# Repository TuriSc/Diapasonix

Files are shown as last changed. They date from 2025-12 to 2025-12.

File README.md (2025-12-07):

# Diapasonix — Portable Electronic Instrument and MIDI Controller

Diapasonix is a portable electronic musical instrument and MIDI controller that is played similarly to a stringed instrument. It features a capacitive touchpad fretboard, I²S audio output, and a built-in synthesizer with chainable audio effects powered by the AMY synthesis engine.

Its four-string, six-fret layout (24 touch points total) can be set up to match traditional stringed instruments like guitar, bass, ukulele, violin, double bass, banjo, and so on. If you can play any of these instruments, you can play Diapasonix!

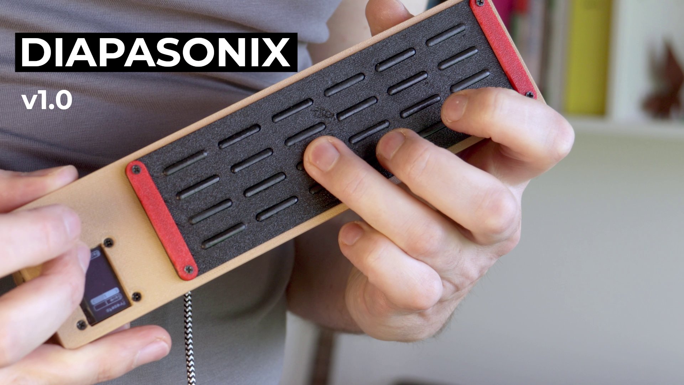
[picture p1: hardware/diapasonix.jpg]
YouTube Video (https://youtu.be/DMDRZ1dwdG4 "Diapasonix")

[Video link](https://youtu.be/DMDRZ1dwdG4)

## Features

* Raspberry Pi Pico 2 (RP2350) as the central unit
* Capacitive touchpad fretboard with 4 strings and 6 frets
* AMY synthesis engine with 256 built-in presets (128 Juno-6 patches, 128 DX7 patches)
* I²S audio output with built-in speaker support and amplified audio output
* SSD1306 OLED display
* Directional switch for navigation and parameter selection
* Multiple audio effects: reverb, chorus, echo/delay, distortion, and low-pass filter
* Per-string tuning and capo transposing
* Strumming mode and tapping mode
* Left-handed mode support
* MIDI output support (optional, can be disabled to use USB as stdio)
* Battery level monitoring and low battery indicator
* Automatic storage and retrieval of settings
* Four user presets for saving and recalling complete instrument configurations
* Volume control
* Display contrast control with automatic dimming

## Synth Engine and Instrument Presets

Diapasonix uses the [AMY](https://github.com/shorepine/amy) synthesis engine, a high-performance fixed-point music synthesizer library. AMY supports multiple synthesis types, but currently Diapasonix offers only the ability to recall any of the 256 built-in presets: 128 patches based on the Juno-6 synthesizer and 128 patches based on the DX7 synthesizer. Each preset has a number (0-255) for easy selection. Pressing the center button while the patch number is selected chooses a patch at random.

## Audio Effects

Diapasonix includes five audio effects that can be enabled and configured:

### Reverb
* Liveness control (room size)
* Damping control
* Crossover frequency

### Chorus
* Maximum delay time
* LFO frequency
* Modulation depth

### Echo/Delay
* Delay time (10-200 ms)
* Feedback amount
* Filter coefficient

### Filter
* Low-pass filter with adjustable cutoff frequency (20 Hz - 20 kHz)
* Resonance (Q factor) control

### Distortion
* Level control (0.0 to 1.0) - amount of distortion effect
* Gain control (1.0 to 2.0) - drive/gain before distortion

## Fretboard and Playing Modes

The fretboard consists of four strings, each with six frets, providing a total of 24 touch points. Two playing modes are available:

**Strumming Mode**: Notes trigger only when you strum across the strings after placing your fingers on frets. In this mode, the last row of frets functions as open strings. When you hold a fret on a string and strum a fret on that last row, the corresponding note of the held fret will play. This mode mimics traditional guitar playing, allows for chord playing, and provides more expressive control.

**Tapping Mode**: Notes trigger immediately when any fret is touched. In this mode, the last row of frets is treated as one more fret on the board, allowing you to continue playing up the string.

The instrument also supports per-string tuning and a capo function for transposition.

## Navigation and Controls

A directional switch (5-way navigation switch) is used to navigate menus and adjust parameters:

* Navigate through menu items using the directional pad
* Press the center button to enter/select
* Long-press the center button to exit or access secondary functions
* Adjust parameter values using directional controls

## Settings

From the settings screen, you can configure:

* **Playing Mode**: Toggle between strumming and tapping modes
* **Left-handed Mode**: Flip both the screen and the entire fretboard orientation, allowing left-handed players to use the instrument naturally
* **Volume**: Adjust output volume (0-8 range)
* **Display Contrast**: Adjust OLED brightness or enable automatic dimming

## Tuning

The tuning screen allows you to:

* Set individual string pitch (default: E2, A2, D3, G3)
* Adjust capo position for transposition
* Fine-tune each string independently

## Presets

Diapasonix includes a preset system that allows you to save and recall complete instrument configurations. Each preset stores a snapshot of:

* Current synth patch number
* All effect states (on/off) and their parameters:
  * Reverb (liveness, damping, crossover)
  * Chorus (max delay, LFO frequency, depth)
  * Echo/Delay (delay time, feedback, filter coefficient)
  * Distortion (level, gain)
  * Filter (cutoff frequency, resonance)
* String tuning (individual pitch for each string)
* Capo position
* Playing mode (strumming or tapping)

## Automatic Save

Diapasonix automatically stores the current settings into its flash memory, with a configurable delay (default 10 seconds) to minimize flash wear. Stored settings are loaded automatically at startup. The Pico onboard LED will flash briefly when data is being written to flash memory. There is a very short gap in the audio output, barely audible, when data is being written to flash.

## Defaults Configuration

All advanced user-configurable options and defaults are defined in the file [config.h](config.h). You can, for example, change pin numbers, MPR121 sensitivity, timing-related values, effect defaults, and enable or disable MIDI output. If you want to change any default configuration options, you'll need to build the sources and generate your own uf2 file to flash to the Pico 2.

## Compiling

Building the sources requires the Raspberry Pi Pico SDK.

```sh
git clone https://github.com/TuriSc/Diapasonix.git
cd Diapasonix
git submodule update --init --recursive
mkdir build && cd build
cmake -DPICO_PLATFORM=rp2350 ..
make
```

## Bill of Materials

* Raspberry Pi Pico 2 (RP235x)
* 2x MPR121 (touch sensors)
* MAX98357 I²S DAC (or similar)
* SSD1306 OLED display (128x64, 0.96")
* Directional switch (5-way navigation switch)
* Speaker (4Ω 3W recommended, but 8Ω 2W is fine too)
* 3.5mm audio jack, switched
* 18650 Lithium battery
* One pair of springs for 18650 battery
* TP4056 (charger module)
* Power switch
* Custom PCB (can be swapped for a diy solution)
* Electrical wire and connectors
* 3D-printed enclosure (printable files are provided, as well as OpenSCAD sources)

## Schematic

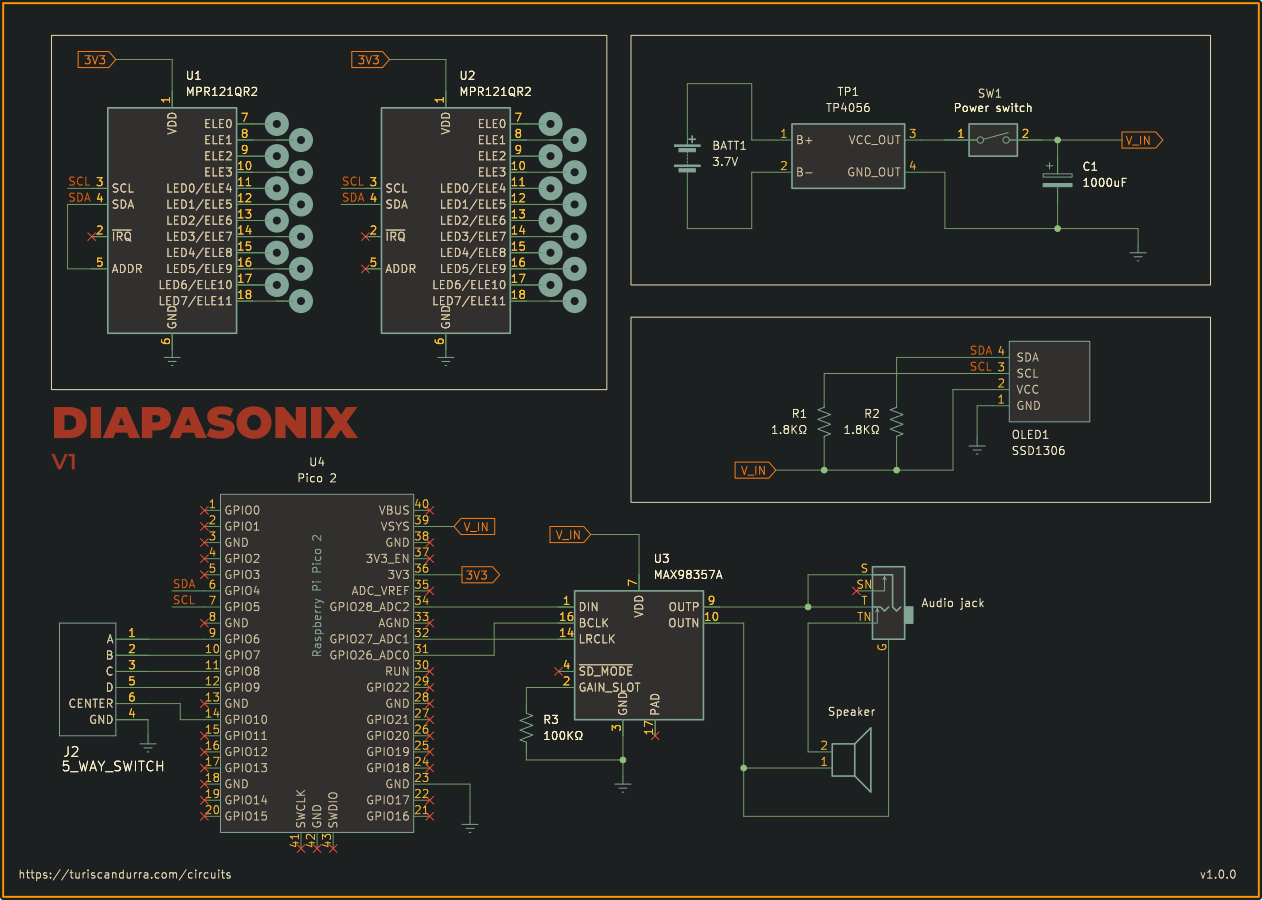
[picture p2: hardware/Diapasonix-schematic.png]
Diapasonix schematic


[PDF version](hardware/Diapasonix-schematic.pdf)

## Construction

I have not yet put together a step-by-step guide to assemble the Diapasonix. I might want to wait until we get to a stable version. I'm changing components and overall design and breaking things as I move. The current capacitive fretboard might undergo a major re-engineering.
One note about the v1 design: the frets are 3d-printed, then dipped in conductive silver paint, and finally coated with a single layer of nail polish. They react very well to even the gentlest of touches.

## Known Limitations

* Synthesizer parameter configuration (beyond patch selection) is planned for future releases.
* Velocity detection is not currently implemented.
* Echo delay is limited to 200ms maximum due to RAM constraints on RP2350.
* A Raspberry Pi Pico (RP2040) will work but with very poor performance, as the audio output will crackle noticeably.
* This is an early prototype. Expect breaking changes.

## Disclaimer

Diapasonix is an original, non‑commercial work created by Turi Scandurra for educational and hobbyist purposes only. The code, schematics, and documentation are provided "as‑is" without any warranties, express or implied.

The author does not claim ownership of any patents that may be relevant to the designs or implementations herein, nor does the author guarantee that the project does not infringe any existing patents, copyrights, trademarks, or other intellectual‑property rights. Users assume all risk associated with the use, modification, or distribution of this material.

By using, copying, or distributing this project you acknowledge that you have read and understood this disclaimer and agree to do so at your own discretion and responsibility.

## More Information

For more information and similar projects, visit [turiscandurra.com/circuits](https://turiscandurra.com/circuits/)

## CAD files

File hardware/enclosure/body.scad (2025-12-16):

include <Diapasonix.scad>
include <shell.scad>

module body(){
    difference(){
        union(){
            shell();
            shell_inner_supports();
        }
        // BOOTSEL opening
        translate([neck_w - bootsel_x, neck_d / 2 - bootsel_y, bootsel_z])
        rotate([0, 0, -90])
        cylinder(h = bootsel_h, r = bootsel_r);
        
        // Tray opening
        margin = pcb_clearance;
        translate([neck_w - tray_inner_w - margin, neck_r1 - margin, 0])
        rotate([0, 90, 0])
        linear_extrude(tray_inner_w + margin)
        intersection(){
            circle(neck_r1 - tray_m + margin, $fn = resolution);
            
            translate([neck_r1 - tray_m - tray_h, -tray_w / 2, 0])
            square([neck_r1 * 2, tray_w + margin * 2]);
        }
        
        // Eyelet insets
        translate([neck_w - wall_d * 2, neck_r1 - margin, 0])
        translate([wall_d * 1.5 - pcb_clearance, tray_w / 2 + tray_eyelet_y_offset, tray_eyelet_z])
        rotate([90, 0, 90])
        linear_extrude(wall_d / 2 + pcb_clearance)
        hull(){
            circle(eyelet_r + pcb_clearance, $fn = resolution);
            translate([-eyelet_r - pcb_clearance, -eyelet_r - pcb_clearance, 0])
            square([eyelet_square_w, eyelet_square_d + pcb_clearance * 2]);
        }
        
        translate([neck_w - wall_d * 2, neck_r1 - margin, 0])
        translate([wall_d * 1.5 - pcb_clearance, -tray_w / 2 - tray_eyelet_y_offset, tray_eyelet_z])
        rotate([-90, 0, -90])
        linear_extrude(wall_d / 2 + pcb_clearance)
        hull(){
            circle(eyelet_r + pcb_clearance, $fn = resolution);
            translate([-eyelet_r - pcb_clearance, -eyelet_r - pcb_clearance, 0])
            square([eyelet_square_w, eyelet_square_d + pcb_clearance * 2]);
        }
        
        // Eyelet screw holes
        translate([neck_w - wall_d * 2, neck_r1 - margin, 0])
        translate([0, tray_w / 2 + tray_eyelet_y_offset, tray_eyelet_z])
        rotate([90, 0, 90])
        translate([0, 0, eyelet_countersunk_z])
        cylinder(h = screw_hole_depth, r = screw_hole_r, $fn = 64);
        
        translate([neck_w - wall_d * 2, neck_r1 - margin, 0])
        translate([0, -tray_w / 2 - tray_eyelet_y_offset, tray_eyelet_z])
        rotate([-90, 0, -90])
        translate([0, 0, eyelet_countersunk_z])
        cylinder(h = screw_hole_depth, r = screw_hole_r, $fn = 64);
        
        // Speaker holes
        translate([neck_w - shell_battery_offset_x + speaker_spacing, neck_d / 2, -neck_r1])
        for (a = [0:7]) {
            rotate(45 * a)
            translate([11, 0, 5])
            cylinder(h = 10, r = 1.4, center = true);
            if(a % 2 == 0){
                rotate(45 * a)
                translate([4.5, 0, 5])
                cylinder(h = 10, r = 1.4, center = true);
            }
        }
        
        // Power switch opening
        translate([neck_w - power_switch_x_offset, neck_d/2,-neck_h])
        cylinder(h=5, r=power_switch_r);
        
        // Audio jack opening
        translate([0, neck_d/2,-jack_z_offset])
        rotate([0,90,0])
        cylinder(h=20, r=jack_r);
    }
    
    // Top face
    difference(){
        union(){
            translate([0, 0, -wall_d])
            cube([neck_w, neck_d, wall_d]);
            
            // Navigation switch support
            translate([neck_w - oled_pos_x + nav_switch_pos_x_offset + nav_switch_pos_y_offset, neck_d / 2 - nav_switch_pos_y_base - wall_d, -nav_switch_pos_h - wall_d])
            cube([nav_switch_cross_w, nav_switch_cross_d - wall_d * 2, wall_d + nav_switch_pos_h]);
            
            // OLED underside supports
            translate([neck_w - oled_pos_x - 5.5, neck_d / 2 - oled_support_top_offset, -wall_d - 2])
            linear_extrude(wall_d)
            polygon([[0, 0], [9, 0], [0, 9]]);
            
            translate([neck_w - oled_pos_x - 5.5, neck_d / 2 + oled_support_bottom_offset, -wall_d - 2])
            linear_extrude(wall_d)
            polygon([[0, 0], [0, 9], [9, 9]]);
            
            translate([neck_w - oled_ribbon_x + oled_ribbon_w, neck_d / 2 - oled_support_top_offset, -wall_d - 2])
            linear_extrude(wall_d)
            polygon([[0, 0], [9, 0], [9, 9]]);
            
            translate([neck_w - oled_ribbon_x + oled_ribbon_w, neck_d / 2 + oled_support_bottom_offset, -wall_d - 2])
            linear_extrude(wall_d)
            polygon([[9, 0], [0, 9], [9, 9]]);
        }
        
        // PCB opening
        translate([wall_d + 2, wall_d + pcb_pos_y_offset + 6.5, -wall_d])
        cube([pcb_w - 4, pcb_d - 13, wall_d]);
    
        // Screw holes, PCB
        translate([wall_d + pcb_screw_offset_x, wall_d + pcb_screw_offset_y + screw_pos_y_offset, -threaded_insert_h])
        cylinder(r = threaded_insert_r, h = threaded_insert_h, $fn = 64);
        
        translate([wall_d + pcb_screw_offset_x, wall_d + pcb_screw_offset_y_bottom + screw_pos_y_offset, -threaded_insert_h])
        cylinder(r = threaded_insert_r, h = threaded_insert_h, $fn = 64);
        
        translate([wall_d + pcb_w - pcb_screw_offset_x, wall_d + pcb_screw_offset_y + screw_pos_y_offset, -threaded_insert_h])
        cylinder(r = threaded_insert_r, h = threaded_insert_h, $fn = 64);
        
        translate([wall_d + pcb_w - pcb_screw_offset_x, wall_d + pcb_screw_offset_y_bottom + screw_pos_y_offset, -threaded_insert_h])
        cylinder(r = threaded_insert_r, h = threaded_insert_h, $fn = 64);
        
        // Screw holes, UI
        translate([neck_w - ui_screw_x_offset, wall_d + pcb_screw_offset_y + screw_pos_y_offset, -threaded_insert_h])
        cylinder(r = threaded_insert_r, h = threaded_insert_h, $fn = 64);
        translate([neck_w - ui_screw_x_offset, neck_d / 2 + oled_screw_y1, -threaded_insert_h])
        cylinder(r = threaded_insert_r, h = threaded_insert_h, $fn = 64);
        
        // OLED opening
        translate([neck_w - oled_pos_x - 5.1, neck_d / 2 - oled_opening_top_offset, -2])
        cube([oled_opening_w, oled_opening_d, 3]);
        
        // Navigation switch opening
        translate([neck_w - oled_pos_x + nav_switch_pos_x_offset + 0.2, neck_d / 2 - nav_switch_pos_y_base, -3.8])
        cube([10.4, 10.8, 10.4]);
    }

    // Standoffs, PCB
    translate([wall_d + pcb_screw_offset_x, wall_d + pcb_screw_offset_y + screw_pos_y_offset, -wall_d - 2])
    standoff(2);
    
    translate([wall_d + pcb_screw_offset_x, wall_d + pcb_screw_offset_y_bottom + screw_pos_y_offset, -wall_d - 2])
    standoff(2);
    
    translate([wall_d + pcb_w - pcb_screw_offset_x, wall_d + pcb_screw_offset_y + screw_pos_y_offset, -wall_d - 2])
    standoff(2);
    
    translate([wall_d + pcb_w - pcb_screw_offset_x, wall_d + pcb_screw_offset_y_bottom + screw_pos_y_offset, -wall_d - 2])
    standoff(2);
    
    // Standoffs, UI
    translate([neck_w - ui_screw_x_offset, neck_d / 2 + oled_screw_y1, -wall_d - 2])
    standoff(2);
    translate([neck_w - ui_screw_x_offset, wall_d + pcb_screw_offset_y + screw_pos_y_offset, -wall_d - 2])
    standoff(2);
}

if(is_undef(is_root)) {
    body();
}

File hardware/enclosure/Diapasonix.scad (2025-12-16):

// v1.1.0
// To be cleaned up, as I tried different construction
// methods and left a trail of unused variables.

resolution = 128; // Adjust as needed
use_threaded_inserts = true;

n_strings = 4;
n_pods_per_string = 6;

pod_w = 25;
pod_d = 10;
pod_h = 2.4;

fret_w = 18;
fret_d = 2;
fret_h = 4; // min is fret_r
fret_r = fret_d/2;
fret_brim_d = 2.2;
fret_brim_h = 0.6;

silicone_h = 1;

magnet_r = 1 + 0.25; // Including clearance
magnet_h = 1 + 0.4; // Including clearance

ridge_d = 2.8;
ridge_h = 3;

ui_w = 58;
capo_offset_w = 7;

wall_d = 2.0;

screw_hole_r = 1.2;
threaded_insert_r = 1.9;
threaded_insert_h = 4;
standoff_r = 3;
so_clr = 0.4;

neck_w = pod_w*n_pods_per_string+ui_w;
neck_d = pod_d*n_strings+ridge_d*n_strings + 2.6;

neck_r1=neck_d/2;
neck_r2=36;
neck_h = neck_r1;

tongue = 1.2;
tongue_h = 4.0;
r_clearance = .4;

tray_w = 25;
tray_h = 20;
tray_m = 2;

neck_top_h = pod_h+ridge_h+fret_r;

// Clearances and tolerances
pcb_clearance = 0.4;
pcb_clearance_2x = pcb_clearance * 2;
header_clearance = 0.4;
switch_clearance = 0.8;
switch_clearance_small = 0.4;
groove_depth = 1.6;
countersunk_depth = 0.4;
countersunk_offset = -0.8;
render_compensation = 0.01;
countersunk_height = 3.2;
screw_hole_depth = 8;

// PCB dimensions
pcb_w = 159.790;
pcb_d = 47.675;
pcb_h = 1;
pcb_screw_offset_x = 4.730;
pcb_screw_offset_y = 3.465;
pcb_screw_offset_y_bottom = 47.625 - 3.465;

// Header dimensions
header_w = 2.75;
header_l = 34;
header_h = 3;
header_oled_l = 12;
header_pos_x = 3.38;
header_pos_y = 4.92;
header_pos_y_offset = 3;
pcb_edge_offset = 1; // Offset from PCB edge
pcb_pos_y_offset = 1; // Y offset for PCB position
screw_pos_y_offset = 1; // Y offset for screw positions

// Capacitive headers cover
cap_header_cover_r = 3.6;
cap_header_cover_dist = 42.66;
cap_header_cover_groove_l = 30.70;
cap_header_cover_screw_y1 = 3.465 + 1;
cap_header_cover_screw_y2_offset = 2.5;
cap_header_cover_top_z = 2;
cap_header_cover_top_h = 2;
cap_header_cover_bottom_z = -10;
cap_header_cover_bottom_h = 10;

// Top opening
top_opening_x = 12.4;
top_opening_w = 137.8;
top_opening_d = 40;
top_opening_y_offset = 4.0;
fret_cutout_x_offset = 2;
fret_cutout_z = 1.4;
fret_spacing = 22.88;

// OLED dimensions
oled_w = 17;
oled_d = 25;
oled_clearance = 0.2;
oled_opening_w = oled_w + oled_clearance * 2;
oled_opening_d = oled_d + oled_clearance * 2;
oled_opening_z = 3;
oled_pos_x = 28.5;
oled_pos_y_offset = 2.7;
oled_support_top_offset = 5.2;
oled_support_bottom_offset = 14.2;
oled_opening_top_offset = 4.6;
oled_screw_y1 = 20.2;
oled_screw_y2 = 1.7;
oled_ribbon_x = 19.0;
oled_ribbon_x_top = 11.5;
oled_ribbon_y_offset = 3.5;
oled_ribbon_w = 4.2;
oled_ribbon_d = 13;
oled_ribbon_z = 3;
oled_ribbon_z_offset = -3;
oled_header_x = 32.2;
oled_header_y_offset = 3.5;
oled_header_z_offset = -0.4;

// Navigation switch
nav_switch_side = 5;
nav_switch_cutout_depth = 4.5;
nav_switch_height = 9;
nav_switch_cutout_size = 3.2;
nav_switch_r = 3.2;
nav_switch_r_outer = nav_switch_r + switch_clearance;
nav_switch_r_opening = 4.4;
nav_switch_cross_w = 6.4;
nav_switch_cross_d = 16;
nav_switch_cross_h = 3;
nav_switch_cutout_r = nav_switch_r + switch_clearance_small;
nav_switch_cutout_h = 1.3;
nav_switch_cutout_z = -2.3;
nav_switch_cutout_square = 1.75;
nav_switch_cutout_square_z = -4;
nav_switch_pos_x_offset = 3;
nav_switch_pos_y_offset = 2.4;
nav_switch_pos_y_offset_top = 5.4;
nav_switch_pos_y_base = 20;
nav_switch_pos_z = 2;
nav_switch_pos_h = 4;
nav_switch_cap_base_z = -1;
nav_switch_cap_base_h = 1.3 + 2.6;
nav_switch_cap_cross_z = 0.6;
nav_switch_import_z = -0.6;

// Audio jack opening
jack_r = 3.5;
jack_z_offset = 10;

// Power switch opening
power_switch_r = 3.5;
power_switch_x_offset = 66;

// UI screw position
ui_screw_x_offset = 4.730;

// Battery holder dimensions
battery_holder_x1 = 9.6;
battery_holder_x2 = 17.4;
battery_holder_y2 = 20;
battery_holder_pos_x = 38;
battery_holder_extrude_w = 80;
battery_socket_w = 65;
battery_socket_d = 18;
battery_socket_clearance = 6;
battery_socket_wall = 2;
battery_socket_h = 20;
battery_terminal_w = 3;
battery_terminal_d = 24;
battery_terminal_neg_x = 32.8;
battery_terminal_neg_y_offset = 12;
battery_terminal_pos_x = -39.5;
battery_terminal_pos_w = 1.5;
battery_terminal_opening_x = -38;
battery_terminal_opening_z = 11;
battery_terminal_opening_h = 72;
battery_terminal_opening_r = 6;
battery_wire_conduit_x = -44;
battery_wire_conduit_y = 18;
battery_wire_conduit_z = 16;
battery_wire_conduit_h = 84;
battery_wire_conduit_r = 3;
battery_symbol_pos_x_plus = -28;
battery_symbol_pos_x_minus = 20;
battery_symbol_y = 9.4;
battery_symbol_z = 10;
battery_symbol_w = 3.2;
battery_symbol_h = 1.2;
battery_symbol_cross_offset = 1;
battery_symbol_cross_z_offset = -1.0;
battery_symbol_cross_h = 3.2;
battery_socket_d_offset = 1; // Additional offset for battery socket depth

// Speaker holder dimensions
speaker_spacing = 37;
speaker_h = 13;
speaker_pos_x1 = -11;
speaker_pos_w1 = 14;
speaker_pos_w2 = 5;
speaker_pos_w2_center = 1.5;
speaker_screw_x1 = 1;
speaker_screw_x2_offset = 1;
speaker_screw_z_offset = 6.2;
speaker_screw_h = 6;

// Chassis dimensions
chassis_x = -56;
chassis_w = 57.8;
chassis_d1 = 20;
chassis_d2 = 14;
chassis_y1 = -10;
chassis_y2 = -7;
chassis_z1 = 0;
chassis_z2 = -6;
chassis_h1 = 2;
chassis_h2 = 0.1;
chassis_cut1_x = -50;
chassis_cut1_y = -11;
chassis_cut1_w1 = 4;
chassis_cut1_w2 = 6;
chassis_cut1_d = 22;
chassis_cut1_z1 = -0.6;
chassis_cut1_z2 = 1.9;
chassis_cut1_x_offset = 2;
chassis_cut2_x = -42;
chassis_cut2_w1 = 16;
chassis_cut2_w2 = 18;
chassis_cut2_x2 = -44;
chassis_cut3_x = -56;
chassis_cut3_y = -3.5;
chassis_cut3_w = 6;
chassis_cut3_d = 7;
chassis_cut3_z = -3;
chassis_cut3_h = 5;
tp4056_pcb_x = -28.2;
tp4056_pcb_y = -9;
tp4056_pcb_w = 28.2;
tp4056_pcb_d = 18;
tp4056_pcb_z = 0.4;
tp4056_pcb_h = 2.4;
tp4056_solder_x = -28.2;
tp4056_solder_y = -8;
tp4056_solder_w = 6;
tp4056_solder_d = 16;
tp4056_solder_z = -0.6;
pico_screw_x = -48.0;
pico_screw_y = 5.68;
pico_screw_h = 6;
amp_screw_x = -54.0;
amp_screw_y = 6.2;
amp_screw_z = -3;
amp_screw_h = 6;
tp4056_stop_x = -25.8;
tp4056_stop_z = -5;
tp4056_stop_h = 5;

// Eyelet dimensions
eyelet_r = 3;
eyelet_square_offset = 3;
eyelet_square_w = 3;
eyelet_square_d = 6;
eyelet_countersunk_z = -1.2;

// Tray dimensions
tray_inner_w = 8;
tray_chassis_offset_x = 2;
tray_chassis_offset_z = -11.4;
tray_eyelet_y_offset = 3;
tray_eyelet_z = -11;
pico_usb_x_offset = 2.5;
pico_usb_z = -19.6;
pico_usb_w = 5;
pico_usb_d = 8.5;
pico_usb_h = 3.4;
pico_pcb_z = -18.2;
pico_pcb_w_clearance = 0.6;
pico_pcb_d = 22;
pico_pcb_h = 1.6;
tp4056_pcb_tray_z = -10.2;
tp4056_socket_z = -8.4;
tp4056_socket_extrude_h = 5;
tp4056_socket_hole_x = 3.6;
tp4056_socket_hole_r = 1.8;
tp4056_led_x = 7.6;
tp4056_led_r = 1.4;
bootsel_x = 13.0;
bootsel_y = 3.5;
bootsel_z = -30;
bootsel_h = 10;
bootsel_r = 1.66;
tray_bottom_screw_x = -5;
tray_bottom_screw_z_offset = 2.0;

// Shell inner supports
shell_battery_offset_x = 212.6;
shell_battery_holder_x = 112;
shell_speaker_offset_x = 13;

$fn=resolution;

function center(x,y,z) = [x/-2,y/-2,z/-2];

module screw_hole(){
    cylinder(r = screw_hole_r, h = screw_hole_depth,$fn=64);
}
    
module standoff(height){
    difference() {
         cylinder(r = standoff_r, h = height,$fn=64);
         cylinder(r = threaded_insert_r, h = height,$fn=64);
    };
}

module countersunk(){
    cylinder(r = screw_hole_r, h = screw_hole_depth,$fn=64);
    translate([0,0,countersunk_height])
    rotate([0,180,0])
    cylinder(h=wall_d, r1=screw_hole_r*2, r2=screw_hole_r);
}

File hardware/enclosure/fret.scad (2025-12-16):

include <Diapasonix.scad>

module fret(mag_holes=true) {
    difference(){
        translate([0, 0, -fret_r * 2 + fret_h])
        union() {
            // Dome
            difference(){
                hull(){
                    translate([fret_r, 0, fret_r])
                    sphere(fret_r);
                    translate([fret_w - fret_r, 0, fret_r])
                    sphere(fret_r);
                }
                translate([0, -fret_r, 0])
                cube([fret_w, fret_d, fret_r]);
            }
            
            // Walls
            translate([0, 0, fret_r])
            rotate([180, 0, 0]) 
            linear_extrude(fret_h - fret_r)
            hull(){
                translate([fret_r, 0, 0])
                circle(fret_r);
                translate([fret_w - fret_r, 0, 0])
                circle(fret_r);
            }
        }
    }
    // Brim
    translate([0, -fret_d/2 - fret_brim_d, 0])
    cube([fret_w, fret_d+fret_brim_d*2, fret_brim_h]);
}

if(is_undef(is_root)) {
    fret();
}

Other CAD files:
hardware/enclosure/headers_cover.scad
hardware/enclosure/navigation_switch_cap.scad
hardware/enclosure/shell.scad
hardware/enclosure/top.scad
hardware/enclosure/tray.scad

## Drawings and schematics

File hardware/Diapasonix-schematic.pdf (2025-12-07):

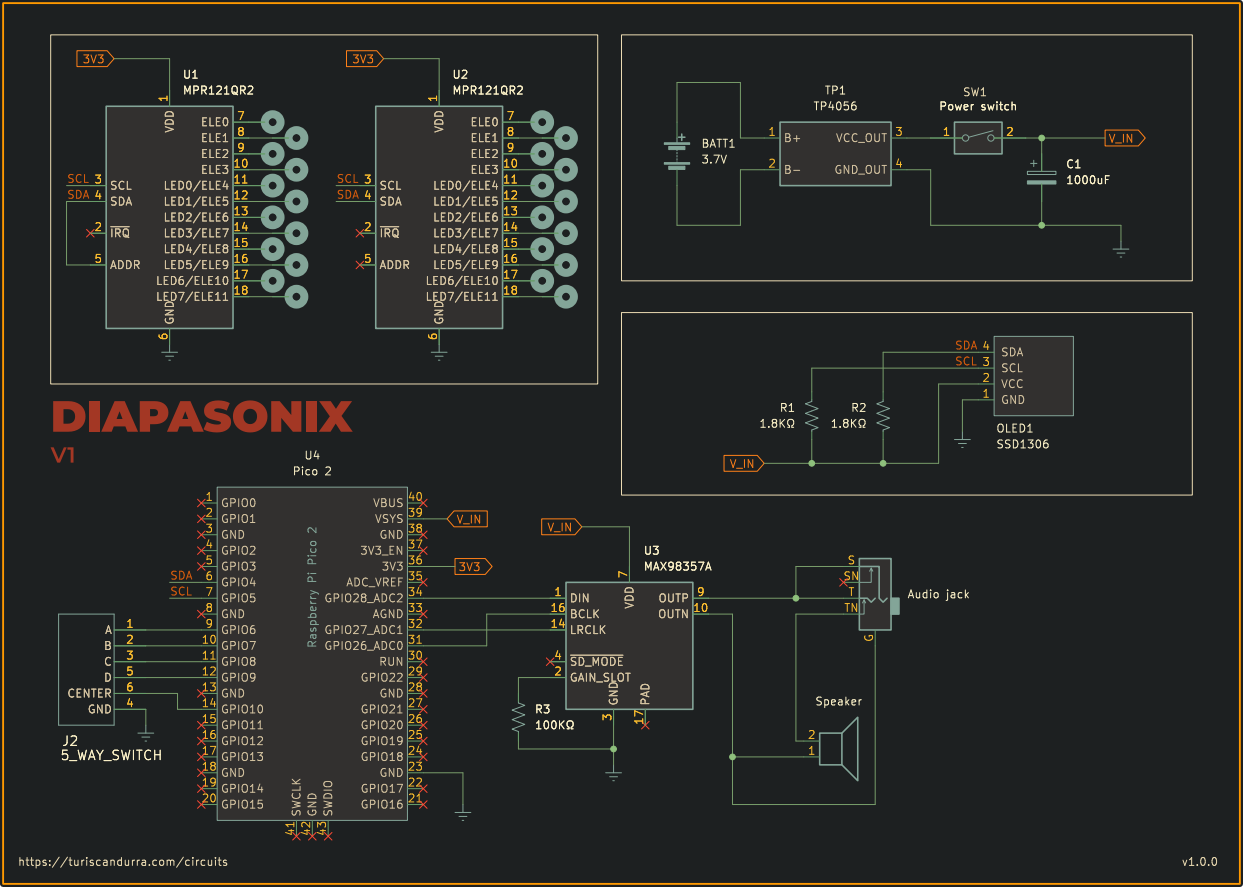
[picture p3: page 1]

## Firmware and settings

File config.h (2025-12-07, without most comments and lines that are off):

#define CONFIG_H_
#define PROGRAM_NAME                "Diapasonix"
#define PROGRAM_VERSION             "1.0.0"
#define PROGRAM_DESCRIPTION         "Portable musical instrument and Midi controller"
#define PROGRAM_URL                 "https://turiscandurra.com/circuits"
#define USB_STR_MANUFACTURER        "TuriScandurra"
#define USB_STR_PRODUCT             "Diapasonix"
#define USE_MIDI                    // Comment out this line to disable Midi output
#define MIDI_NOTE_MAX               127
#define MIDI_NOTE_ON                0x90
#define MIDI_NOTE_OFF               0x80
#define F_CPU                       225000000
#define F_CPU_MOD_KHZ               226000
#define F_SAMP                      44140
#define VCO_FREQ                    1356000000
#define PLL_PD1                     6
#define PLL_PD2                     1
#define NUM_STRINGS                 4
#define NUM_FRETS                   6
#define FRETBOARD_LAYOUT { \
                                        {12, 13, 14, 15, 16, 17}, \
                                        {18, 19, 20, 21, 22, 23}, \
                                        {11, 10,  9,  8,  7,  6}, \
                                        { 5,  4,  3,  2,  1,  0} \
}
#define PICO_DEFAULT_FLOAT_IMPL         pico
#define USE_AUDIO_I2S                   1
#define PICO_AUDIO_I2S_DATA_PIN         28 // I2S DIN
#define PICO_AUDIO_I2S_CLOCK_PIN_BASE   26 // I2S BCK
#define DEFAULT_PATCH              226
#define DEFAULT_VOLUME             3 // 0-8 range, gets converted to AMY's 0-11.0 range
#define DEFAULT_STRING_PITCH_0     55 // G3
#define DEFAULT_STRING_PITCH_1     50 // D3
#define DEFAULT_STRING_PITCH_2     45 // A2
#define DEFAULT_STRING_PITCH_3     40 // E2
#define DIAPASONIX_REVERB_DEFAULT_LIVENESS     0.85f
#define DIAPASONIX_REVERB_DEFAULT_DAMPING      0.5f
#define DIAPASONIX_REVERB_DEFAULT_XOVER_HZ     3000.0f
#define DIAPASONIX_CHORUS_DEFAULT_MAX_DELAY    320
#define DIAPASONIX_CHORUS_DEFAULT_LFO_FREQ     0.5f
#define DIAPASONIX_CHORUS_DEFAULT_MOD_DEPTH    0.5f
#define DIAPASONIX_ECHO_DEFAULT_DELAY_MS       150.0f
#define DIAPASONIX_ECHO_DEFAULT_FEEDBACK       0.75f
#define DIAPASONIX_ECHO_DEFAULT_FILTER_COEF    0.0f
#define DIAPASONIX_ECHO_DEFAULT_MAX_DELAY_MS   200.0f  // 200ms requires ~65KB for 2 channels (vs 131KB for 400ms).
#define DIAPASONIX_FILTER_DEFAULT_FREQ_HZ      1000.0f  // 1 kHz cutoff
#define DIAPASONIX_FILTER_DEFAULT_RESONANCE    0.7f     // Default Q factor
#define DIAPASONIX_DISTORTION_DEFAULT_LEVEL    0.75f    // 0.0 to 1.0 - amount of distortion
#define DIAPASONIX_DISTORTION_DEFAULT_GAIN     10.0f    // 10.0 to 20.0 internally (displayed as 1.0 to 2.0 in UI) - drive/gain before distortion
#define I2C_PORT                    i2c0
#define SDA_PIN                     4 // i2c0
#define SCL_PIN                     5 // i2c0
#define I2C_FREQ                    400 * 1000 // 400kHz
#define MPR121_ADDRESS              0x5A
#define MPR121_ADDRESS_1            0x5C // ADDR tied to SDA. Make sure your module is not shorting ADD to GND.
#define MPR121_TOUCH_THRESHOLD      22   // These values might have to be adjusted based on the
#define MPR121_RELEASE_THRESHOLD    16   // size of your electrodes and their distance from the chip.
#define MPR121_DEBOUNCE_TIME_MS     20   // Ignore touches within 20ms of previous events.
#define SSD1306_ADDRESS             0x3C
#define SSD1306_WIDTH               128
#define SSD1306_HEIGHT              64
#define SSD1306_ROTATION            1    // Rotate the display by 90°
#define DS_A                        6
#define DS_B                        7
#define DS_C                        8
#define DS_D                        9
#define DS_X                        10   // Center switch
#define LONG_PRESS_THRESHOLD        750  // Amount of ms to hold the button to trigger a long press
#define FRET_RELEASE_TOLERANCE_MS   25   // When a fret is released, still consider it touched for this many ms.
#define STATE_SNAPSHOT_WINDOW_MS    100  // When strumming, look back this many ms to determine which frets were touched.
#define FRET_STALE_TIMEOUT_MS       5000 // Maximum age for touch/release times before they're considered stale.
#define FRET_VERY_RECENT_THRESHOLD_MS 50 // Threshold for considering a touch "very recent".
#define FRET_POST_STRUM_THRESHOLD_MS 30  // Threshold after a strum where frets pressed are treated
#define OPEN_STRING_SUSTAIN_TIME_MS 3000  // Time that open string notes continue playing after
#define FRET_RELEASE_DELAY_MS       50   // Threshold for delaying note off when descending quickly
#define DISPLAY_DIM_DELAY           5     // Seconds since last UI interaction for the screen
#define BATT_LVL_PIN                29
#define USE_FLASH_STORAGE           true // Set to false to disable flash storage (both reading and writing)
#define FLASH_TARGET_OFFSET         (FLASH_SECTOR_SIZE * 511)
#define MAGIC_NUMBER                {0x44, 0x50, 0x53, 0x58} // 'DPSX' - Diapasonix magic number
#define MAGIC_NUMBER_LENGTH         4
#define FLASH_WRITE_DELAY_S         10  // To minimize flash operations, delay writing by this amount of seconds.
#define NUM_PRESETS                 4
#define PRESET_0_PATCH              DEFAULT_PATCH
#define PRESET_0_FX_REVERB          0
#define PRESET_0_FX_FILTER          0
#define PRESET_0_FX_CHORUS          0
#define PRESET_0_FX_ECHO            0
#define PRESET_0_FX_DISTORTION      0
#define PRESET_0_REVERB_LIVENESS    DIAPASONIX_REVERB_DEFAULT_LIVENESS
#define PRESET_0_REVERB_DAMPING     DIAPASONIX_REVERB_DEFAULT_DAMPING
#define PRESET_0_REVERB_XOVER_HZ    DIAPASONIX_REVERB_DEFAULT_XOVER_HZ
#define PRESET_0_CHORUS_MAX_DELAY   DIAPASONIX_CHORUS_DEFAULT_MAX_DELAY
#define PRESET_0_CHORUS_LFO_FREQ    DIAPASONIX_CHORUS_DEFAULT_LFO_FREQ
#define PRESET_0_CHORUS_DEPTH       DIAPASONIX_CHORUS_DEFAULT_MOD_DEPTH
#define PRESET_0_ECHO_DELAY_MS      DIAPASONIX_ECHO_DEFAULT_DELAY_MS
#define PRESET_0_ECHO_FEEDBACK      DIAPASONIX_ECHO_DEFAULT_FEEDBACK
#define PRESET_0_ECHO_FILTER_COEF   DIAPASONIX_ECHO_DEFAULT_FILTER_COEF
#define PRESET_0_FILTER_FREQ_HZ     DIAPASONIX_FILTER_DEFAULT_FREQ_HZ
#define PRESET_0_FILTER_RESONANCE   DIAPASONIX_FILTER_DEFAULT_RESONANCE
#define PRESET_0_DISTORTION_LEVEL   DIAPASONIX_DISTORTION_DEFAULT_LEVEL
#define PRESET_0_DISTORTION_GAIN    DIAPASONIX_DISTORTION_DEFAULT_GAIN
#define PRESET_0_STRING_PITCH_0     DEFAULT_STRING_PITCH_0
#define PRESET_0_STRING_PITCH_1     DEFAULT_STRING_PITCH_1
#define PRESET_0_STRING_PITCH_2     DEFAULT_STRING_PITCH_2
#define PRESET_0_STRING_PITCH_3     DEFAULT_STRING_PITCH_3
#define PRESET_0_CAPO               0
#define PRESET_0_PLAYING_MODE       0   // Tapping mode
#define PRESET_1_PATCH              241
#define PRESET_1_FX_REVERB          1
#define PRESET_1_FX_FILTER          0
#define PRESET_1_FX_CHORUS          0
#define PRESET_1_FX_ECHO            0
#define PRESET_1_FX_DISTORTION      0
#define PRESET_1_REVERB_LIVENESS    DIAPASONIX_REVERB_DEFAULT_LIVENESS
#define PRESET_1_REVERB_DAMPING     DIAPASONIX_REVERB_DEFAULT_DAMPING
#define PRESET_1_REVERB_XOVER_HZ    DIAPASONIX_REVERB_DEFAULT_XOVER_HZ
#define PRESET_1_CHORUS_MAX_DELAY   DIAPASONIX_CHORUS_DEFAULT_MAX_DELAY
#define PRESET_1_CHORUS_LFO_FREQ    DIAPASONIX_CHORUS_DEFAULT_LFO_FREQ
#define PRESET_1_CHORUS_DEPTH       DIAPASONIX_CHORUS_DEFAULT_MOD_DEPTH
#define PRESET_1_ECHO_DELAY_MS      DIAPASONIX_ECHO_DEFAULT_DELAY_MS
#define PRESET_1_ECHO_FEEDBACK      DIAPASONIX_ECHO_DEFAULT_FEEDBACK
#define PRESET_1_ECHO_FILTER_COEF   DIAPASONIX_ECHO_DEFAULT_FILTER_COEF
#define PRESET_1_FILTER_FREQ_HZ     DIAPASONIX_FILTER_DEFAULT_FREQ_HZ
#define PRESET_1_FILTER_RESONANCE   DIAPASONIX_FILTER_DEFAULT_RESONANCE
#define PRESET_1_DISTORTION_LEVEL   DIAPASONIX_DISTORTION_DEFAULT_LEVEL
#define PRESET_1_DISTORTION_GAIN    DIAPASONIX_DISTORTION_DEFAULT_GAIN
#define PRESET_1_STRING_PITCH_0     DEFAULT_STRING_PITCH_0
#define PRESET_1_STRING_PITCH_1     DEFAULT_STRING_PITCH_1
#define PRESET_1_STRING_PITCH_2     DEFAULT_STRING_PITCH_2
#define PRESET_1_STRING_PITCH_3     DEFAULT_STRING_PITCH_3
#define PRESET_1_CAPO               0
#define PRESET_1_PLAYING_MODE       0   // Tapping mode
#define PRESET_2_PATCH              40
#define PRESET_2_FX_REVERB          0
#define PRESET_2_FX_FILTER          0
#define PRESET_2_FX_CHORUS          1
#define PRESET_2_FX_ECHO            0
#define PRESET_2_FX_DISTORTION      0
#define PRESET_2_REVERB_LIVENESS    DIAPASONIX_REVERB_DEFAULT_LIVENESS
#define PRESET_2_REVERB_DAMPING     DIAPASONIX_REVERB_DEFAULT_DAMPING
#define PRESET_2_REVERB_XOVER_HZ    DIAPASONIX_REVERB_DEFAULT_XOVER_HZ
#define PRESET_2_CHORUS_MAX_DELAY   DIAPASONIX_CHORUS_DEFAULT_MAX_DELAY
#define PRESET_2_CHORUS_LFO_FREQ    DIAPASONIX_CHORUS_DEFAULT_LFO_FREQ
#define PRESET_2_CHORUS_DEPTH       DIAPASONIX_CHORUS_DEFAULT_MOD_DEPTH
#define PRESET_2_ECHO_DELAY_MS      DIAPASONIX_ECHO_DEFAULT_DELAY_MS
#define PRESET_2_ECHO_FEEDBACK      DIAPASONIX_ECHO_DEFAULT_FEEDBACK
#define PRESET_2_ECHO_FILTER_COEF   DIAPASONIX_ECHO_DEFAULT_FILTER_COEF
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

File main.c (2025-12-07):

/* Diapasonix
 * Portable electronic instrument and Midi controller
 * with capacitive touchpad fretboard, built-in synth and speaker.
 * By Turi Scandurra – https://turiscandurra.com/circuits
 */
 
#include <stdio.h>

#include "pico/stdlib.h"
#include "hardware/clocks.h"
#include "hardware/structs/clocks.h"
#include "pico/multicore.h"
#include "hardware/adc.h"   // Used for low battery detection
#include "pico/binary_info.h"

#include "amy.h"

#include "config.h"
#include "audio/audio_i2s.h"
#include "multicore_audio.h"
#include "ssd1306.h"
#include "battery-check.h"

#include "global_filter.h"
#include "global_distortion.h"
#include "state_data.h"
#include "touch.h"
#include "flash.h"
#include "fretboard.h"
#include "display/display.h"
#include "directional_switch.h"

#if defined (USE_MIDI)
#include "bsp/board_api.h"  // For TinyUSB Midi
#include "tusb.h"           // For TinyUSB Midi
#endif

/* Globals */

state_data_t* state_data;

static alarm_id_t power_on_alarm_id;
struct audio_buffer_pool *ap;

ssd1306_t display;

amy_event e[NUM_STRINGS];

#if defined (USE_MIDI)
/* MIDI helper function */
static inline uint32_t tud_midi_write24 (uint8_t jack_id, uint8_t b1, uint8_t b2, uint8_t b3) {
    // Use static array to avoid stack corruption when called from multiple contexts
    // But ensure thread-safety by copying values immediately
    uint8_t msg[3];
    msg[0] = b1;
    msg[1] = b2;
    msg[2] = b3;
    
    // Validate MIDI note range before sending
    if(b1 == MIDI_NOTE_ON || b1 == MIDI_NOTE_OFF) {  // Note on or note off
        if(b2 > MIDI_NOTE_MAX) {
            // Invalid note - don't send
            return 0;
        }
    }
    
    return tud_midi_stream_write(jack_id, msg, 3);
}
#endif

/* Note and audio */

int64_t power_on_complete() {
    gpio_put(PICO_DEFAULT_LED_PIN, 0);
    return 0;
}

void note_on(uint8_t string, uint8_t note) {
    // Validate string is within bounds
    if(string >= NUM_STRINGS) {
        return;  // Invalid string index
    }
    
    // Validate note is within MIDI range
    if(note > MIDI_NOTE_MAX) {
        return;  // Invalid note
    }
    
    float velocity = 0.5;
    e[string] = amy_default_event();
    e[string].time = 0;
    e[string].synth = string;  // Each string is its own instrument
    e[string].midi_note = note;
    e[string].velocity = velocity;
    amy_add_event(&e[string]);
    
#if defined (USE_MIDI)
    // Send MIDI note on message (MIDI_NOTE_ON = note on, channel 0)
    // Double-check note value before sending to MIDI
    uint8_t midi_note = note;
    if(midi_note > MIDI_NOTE_MAX) {
        midi_note = MIDI_NOTE_MAX;  // Clamp to valid range
    }
    
    uint8_t midi_velocity = (uint8_t)(velocity * MIDI_NOTE_MAX);
    tud_midi_write24(0, MIDI_NOTE_ON, midi_note, midi_velocity);
#endif
}

void note_off(uint8_t string, uint8_t note) {
    if(string >= NUM_STRINGS) {
        return;
    }
    
    e[string] = amy_default_event();
    e[string].time = 0;
    e[string].synth = string;
    e[string].midi_note = note;
    e[string].velocity = 0;  // velocity = 0 means note off
    amy_add_event(&e[string]);
    
#if defined (USE_MIDI)
    // Send MIDI note off message (MIDI_NOTE_OFF = note off, channel 0)
    tud_midi_write24(0, MIDI_NOTE_OFF, note, 0);
#endif
}

void power_on_led() {
    gpio_init(PICO_DEFAULT_LED_PIN);
    gpio_set_dir(PICO_DEFAULT_LED_PIN, GPIO_OUT);
    gpio_put(PICO_DEFAULT_LED_PIN, 1);
    if (power_on_alarm_id > 0) {
        cancel_alarm(power_on_alarm_id);
    }
    power_on_alarm_id = add_alarm_in_ms(500, power_on_complete, NULL, true);
}

void intro_complete() {
    set_context(CTX_MAIN);
    set_selection(SELECTION_PATCH);
    display_draw(&display);
}

// Exported functions
void update_display() {
    if(get_contrast() == CONTRAST_AUTO) {
        display_wake(&display);
    }
    set_draw_pending(true);
}

void update_patch() {
    uint16_t patch_num = get_patch();
    
    // Set up each string as its own instrument
    for(uint8_t i = 0; i < NUM_STRINGS; i++) {
        // Create an event to load the patch for this string/instrument
        e[i] = amy_default_event();
        e[i].time = 0;
        e[i].synth = i;                 // Each string is instrument 0, 1, 2, 3
        e[i].patch_number = patch_num;  // Load the selected patch
        e[i].num_voices = 1;            // Just one voice per string
        amy_add_event(&e[i]);
    }
}

void update_tuning() {
    set_draw_pending(true);
}

void update_volume() {
    // Convert UI volume (0-8) to AMY volume (0-11.0 float)
    uint8_t ui_volume = get_volume();
    float amy_volume;
    
    if (ui_volume == 0) {
        amy_volume = 0.0f;
    } else {
        amy_volume = ((float)ui_volume / 8.0f) * 11.0f;
    }
        
    // Set AMY global volume directly
    amy_global.volume = amy_volume;
}

void update_fx(amy_fx_t fx) {
    switch(fx){
        case REVERB:
            config_reverb((float)get_fx(REVERB)*2.0f, get_reverb_liveness(), get_reverb_damping(), get_reverb_xover_hz());
        break;
        case CHORUS:
            config_chorus((float)get_fx(CHORUS)*2.0f, get_chorus_max_delay(), get_chorus_lfo_freq(), get_chorus_depth());
        break;
        case ECHO:
        {
            // Ensure AMY is running and echo feature is enabled before configuring echo
            if (!amy_global.running || !AMY_HAS_ECHO) {
                break;
            }
            
            float level = (float)get_fx(ECHO)*2.0f;
            
            config_echo(level, get_echo_delay_ms(), DIAPASONIX_ECHO_DEFAULT_MAX_DELAY_MS, get_echo_feedback(), get_echo_filter_coef());
        }
        break;
        case FILTER:
        {
            bool enabled = get_fx(FILTER);
            global_filter_set_enabled(enabled);
            if (enabled) {
                config_global_filter(get_filter_freq_hz(), get_filter_resonance());
            }
        }
        break;
        case DISTORTION:
        {
            bool enabled = get_fx(DISTORTION);
            global_distortion_set_enabled(enabled);
            if (enabled) {
                config_global_distortion(get_distortion_level(), get_distortion_gain());
            }
        }
        break;
    }
}

void initialize_default_settings() {
    // Settings not loaded, initialize state_data with default values
    set_patch(DEFAULT_PATCH);

    set_fx(REVERB, false);
    set_fx(FILTER, false);
    set_fx(CHORUS, false);
    set_fx(ECHO, false);
    set_fx(DISTORTION, false);
    
    // Initialize effect parameters with defaults
    set_reverb_liveness(DIAPASONIX_REVERB_DEFAULT_LIVENESS);
    set_reverb_damping(DIAPASONIX_REVERB_DEFAULT_DAMPING);
    set_reverb_xover_hz(DIAPASONIX_REVERB_DEFAULT_XOVER_HZ);
    
    set_chorus_max_delay(DIAPASONIX_CHORUS_DEFAULT_MAX_DELAY);
    set_chorus_lfo_freq(DIAPASONIX_CHORUS_DEFAULT_LFO_FREQ);
    set_chorus_depth(DIAPASONIX_CHORUS_DEFAULT_MOD_DEPTH);
    
    set_echo_delay_ms(DIAPASONIX_ECHO_DEFAULT_DELAY_MS);
    set_echo_feedback((float)DIAPASONIX_ECHO_DEFAULT_FEEDBACK);
    set_echo_filter_coef((float)DIAPASONIX_ECHO_DEFAULT_FILTER_COEF);
    
    // TODO: Add filter type. The only available filter is LPF24,
    // but AMY also supports HPF, BPF, and LPF.
    set_filter_freq_hz(DIAPASONIX_FILTER_DEFAULT_FREQ_HZ);
    set_filter_resonance(DIAPASONIX_FILTER_DEFAULT_RESONANCE);
    
    set_distortion_level(DIAPASONIX_DISTORTION_DEFAULT_LEVEL);
    set_distortion_gain(DIAPASONIX_DISTORTION_DEFAULT_GAIN);
    
    set_volume(DEFAULT_VOLUME); // 0-8 range, gets converted to AMY's 0-11.0 range
    set_contrast(CONTRAST_AUTO); // Automatic dimming of display brightness

    set_string_pitch(0, DEFAULT_STRING_PITCH_0); // G3
    set_string_pitch(1, DEFAULT_STRING_PITCH_1); // D3
    set_string_pitch(2, DEFAULT_STRING_PITCH_2); // A2
    set_string_pitch(3, DEFAULT_STRING_PITCH_3); // E2

    set_playing_mode(false); // Start in tapping mode
    set_lefthanded(false);
    
    set_preset_selected(-1); // No preset selected initially
    
    // Initialize advanced timing parameters with defaults
    set_state_snapshot_window_ms(STATE_SNAPSHOT_WINDOW_MS);
    set_fret_stale_timeout_ms(FRET_STALE_TIMEOUT_MS);
    set_fret_very_recent_threshold_ms(FRET_VERY_RECENT_THRESHOLD_MS);
    set_fret_post_strum_threshold_ms(FRET_POST_STRUM_THRESHOLD_MS);
    set_fret_release_delay_ms(FRET_RELEASE_DELAY_MS);
}

/* Low battery */
void battery_low_detected() {
    set_low_batt(true);
    battery_check_stop(); // Stop the timer
}

/* Binary information */
void bi_decl_all() {
    bi_decl(bi_program_name(PROGRAM_NAME));
    bi_decl(bi_program_description(PROGRAM_DESCRIPTION));
    bi_decl(bi_program_version_string(PROGRAM_VERSION));
    bi_decl(bi_program_url(PROGRAM_URL));
    bi_decl(bi_1pin_with_name(BATT_LVL_PIN, "Battery sensing pin"));
    
    // I2C pins
    bi_decl(bi_2pins_with_func(SDA_PIN, SCL_PIN, GPIO_FUNC_I2C));
    bi_decl(bi_1pin_with_name(SDA_PIN, "SDA"));
    bi_decl(bi_1pin_with_name(SCL_PIN, "SCL"));

    // I2S audio pins
    bi_decl(bi_1pin_with_name(PICO_AUDIO_I2S_DATA_PIN, "I2S DIN"));
    bi_decl(bi_1pin_with_name(PICO_AUDIO_I2S_CLOCK_PIN_BASE, "I2S BCK"));
    bi_decl(bi_1pin_with_name(PICO_AUDIO_I2S_CLOCK_PIN_BASE + 1, "I2S LRCK"));
    
    // Directional switch pins
    bi_decl(bi_1pin_with_name(DS_A, "DS_A"));
    bi_decl(bi_1pin_with_name(DS_B, "DS_B"));
    bi_decl(bi_1pin_with_name(DS_C, "DS_C"));
    bi_decl(bi_1pin_with_name(DS_D, "DS_D"));
    bi_decl(bi_1pin_with_name(DS_X, "DS_X (Center)"));
}

/* MIDI stubs */
void run_midi() {
    (void)0; // No-op
}

void amy_send_midi_note_on(uint16_t osc) {
    (void)osc; // No-op
}

void amy_send_midi_note_off(uint16_t osc) {
    (void)osc; // No-op
}

int main() {
    // Overclock to 226MHz
    set_sys_clock_pll(VCO_FREQ, PLL_PD1, PLL_PD2); 

    stdio_init_all();

    // Use the onboard LED as a power-on indicator
    power_on_led();

    printf("%s\n", USB_STR_PRODUCT);
    printf("\n");
    printf("Clock is set to %d\n", clock_get_hz(clk_sys));

    gpio_init(SDA_PIN);
    gpio_init(SCL_PIN);
    gpio_set_function(SDA_PIN, GPIO_FUNC_I2C);
    gpio_set_function(SCL_PIN, GPIO_FUNC_I2C);
    gpio_pull_up(SDA_PIN);
    gpio_pull_up(SCL_PIN);

    i2c_init(I2C_PORT, I2C_FREQ);
    display_init(&display);

    // Initialize the touch modules
    mpr121_initialize();

    bi_decl_all();

    directional_switch_init();

    // Initialize the ADC, used for voltage sensing
    adc_init();
    // Launch the battery check timed task
    battery_check_init(5000, NULL, (void*)battery_low_detected);

    // Set state data
    set_context(CTX_INIT);
    set_dirty(false);
    set_low_batt(false);
    // Attempt to load previous settings, if stored on flash
    bool data_loaded = load_flash_data();
    if(!data_loaded) {
        initialize_default_settings();
    }
    // Clear dirty flag after loading to prevent writing back the same data we just loaded
    set_dirty(false);

    // Initialize AMY synthesis engine
    amy_config_t amy_config = amy_default_config();
    amy_config.audio = AMY_AUDIO_IS_NONE;  // Using custom I2S
    amy_config.features.default_synths = 0;
    amy_config.features.echo = 1;  // Explicitly enable echo feature
    amy_start(amy_config);
    
    // Initialize global filter
    global_filter_init();
    global_distortion_init();
    
    // Wait a little for AMY initialization to complete
    sleep_ms(100);

    // Launch Core1 for multicore audio processing
    multicore_launch_core1(core1_main);

    // Wait for Core1 ready signal
    await_message_from_other_core();
    
    amy_global.running = 1;

    sleep_ms(250);

    // Apply all loaded settings to the audio engine, so
    // effects are properly enabled/configured after loading from flash.
    update_patch();
    update_fx(REVERB);
    update_fx(CHORUS);
    update_fx(ECHO);
    update_fx(FILTER);
    update_fx(DISTORTION);
    update_tuning();
    update_volume();

    // Init i2s audio
    ap = init_audio();

    // Show a short intro animation. This will distract the user
    // while the hardware is calibrating.
    play_intro_animation(&display, intro_complete);
    set_context(CTX_MAIN);
    set_selection(SELECTION_PATCH);
    display_draw(&display);

#if defined (USE_MIDI)
    // Enable Midi device functionality
    board_init();
    tud_init(BOARD_TUD_RHPORT);

    if (board_init_after_tusb) {
        board_init_after_tusb();
    }
#endif

    // Apply settings that were set at startup
    update_patch();
    update_volume();

    while(true) { // Main loop
        // Perform any pending flash writes before audio operations
        // to ensures Core1 is not reset while audio is being processed.
        flash_write_task();
        
        directional_switch_task(); // Poll buttons

        mpr121_task();

        delay_ms(5); // Amy's idle function
        display_task(&display); // Poll display updates after audio as display I2C can be such a block
        
#if defined (USE_MIDI)
        tud_task(); // TinyUSB device task
#endif
    }
    return 0;
}

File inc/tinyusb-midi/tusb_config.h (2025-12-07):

/*
 * The MIT License (MIT)
 *
 * Copyright (c) 2019 Ha Thach (tinyusb.org)
 *
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
 */

#ifndef _TUSB_CONFIG_H_
#define _TUSB_CONFIG_H_

#ifdef __cplusplus
 extern "C" {
#endif

// RHPort number used for device can be defined by board.mk, default to port 0
#ifndef BOARD_TUD_RHPORT
#define BOARD_TUD_RHPORT      0
#endif

// RHPort max operational speed can defined by board.mk
#ifndef BOARD_TUD_MAX_SPEED
#define BOARD_TUD_MAX_SPEED   OPT_MODE_DEFAULT_SPEED
#endif

//--------------------------------------------------------------------
// COMMON CONFIGURATION
//--------------------------------------------------------------------

// defined by board.mk
#ifndef CFG_TUSB_MCU
  #error CFG_TUSB_MCU must be defined
#endif

#ifndef CFG_TUSB_OS
#define CFG_TUSB_OS                 OPT_OS_PICO
#endif

// CFG_TUSB_DEBUG is defined by compiler in DEBUG build
// #ifndef CFG_TUSB_DEBUG
// #define CFG_TUSB_DEBUG        0
// #endif

// Enable Device stack
#define CFG_TUD_ENABLED       1

// Default is max speed that hardware controller could support with on-chip PHY
#define CFG_TUD_MAX_SPEED     BOARD_TUD_MAX_SPEED

/* USB DMA on some MCUs can only access a specific SRAM region with restriction on alignment.
 * Tinyusb use follows macros to declare transferring memory so that they can be put
 * into those specific section.
 * e.g
 * - CFG_TUSB_MEM SECTION : __attribute__ (( section(".usb_ram") ))
 * - CFG_TUSB_MEM_ALIGN   : __attribute__ ((aligned(4)))
 */
#ifndef CFG_TUSB_MEM_SECTION
#define CFG_TUSB_MEM_SECTION
#endif

#ifndef CFG_TUSB_MEM_ALIGN
#define CFG_TUSB_MEM_ALIGN          __attribute__ ((aligned(4)))
#endif

//--------------------------------------------------------------------
// DEVICE CONFIGURATION
//--------------------------------------------------------------------

#ifndef CFG_TUD_ENDPOINT0_SIZE
#define CFG_TUD_ENDPOINT0_SIZE    64
#endif

//------------- CLASS -------------//
#define CFG_TUD_CDC               0
#define CFG_TUD_MSC               0
#define CFG_TUD_HID               0
#define CFG_TUD_MIDI              1
#define CFG_TUD_VENDOR            0

// MIDI FIFO size of TX and RX
#define CFG_TUD_MIDI_RX_BUFSIZE   (TUD_OPT_HIGH_SPEED ? 512 : 64)
#define CFG_TUD_MIDI_TX_BUFSIZE   (TUD_OPT_HIGH_SPEED ? 512 : 64)

#ifdef __cplusplus
 }
#endif

#endif /* _TUSB_CONFIG_H_ */

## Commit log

2025-12-16 Enclosure v1.1.0
    [Diapasonix.scad, body.scad, fret.scad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]
2025-12-16 Add power switch and audio jack openings to enclosure body
    [Diapasonix.scad, body.scad]
